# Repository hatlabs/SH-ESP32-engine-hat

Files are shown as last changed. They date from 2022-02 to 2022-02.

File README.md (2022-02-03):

# Engine Top Hat for SH-ESP32

This repository contains the hardware design files for the Engine Top Hat for SH-ESP32 (Engine Hat for short).

Engine Hat is a add-on circuit board that provides useful circuitry for connecting tachometers (RPM sensors), tank level sensors and engine alarms to an [SH-ESP32](https://hatlabs.github.io/sh-esp32).

The SH-ESP32 Engine Hat will be eventually available for purchase at [hatlabs.fi](https://hatlabs.fi).

Top view:

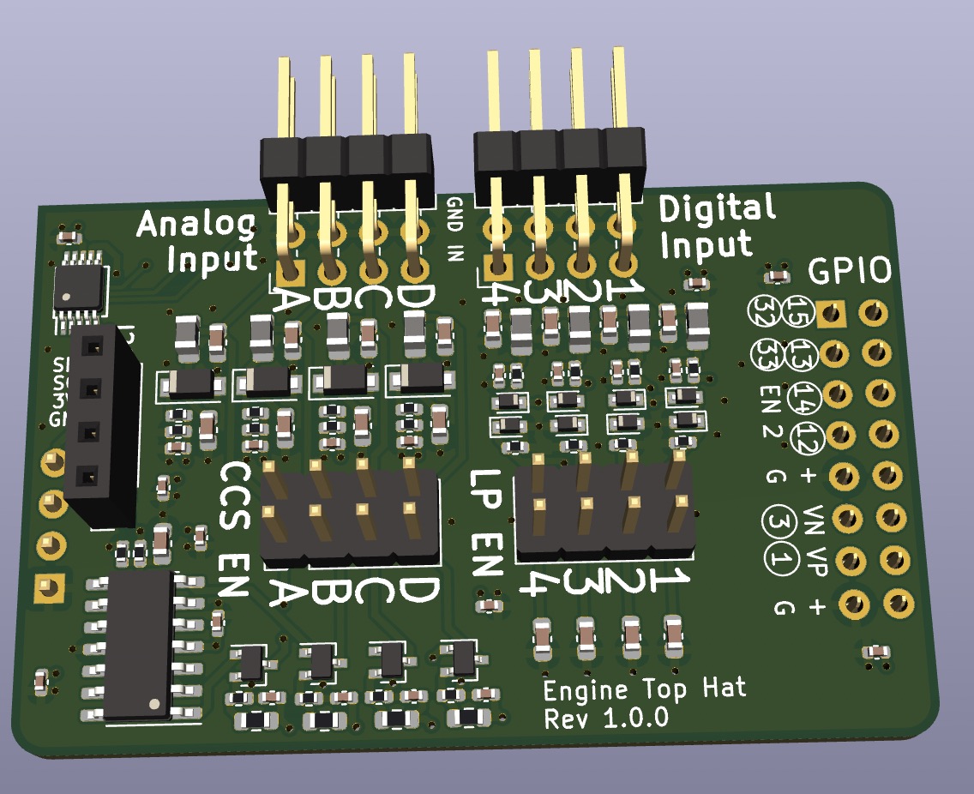
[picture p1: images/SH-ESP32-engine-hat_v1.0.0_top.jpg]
Rev 1.0.0 board, top view


Bottom view:

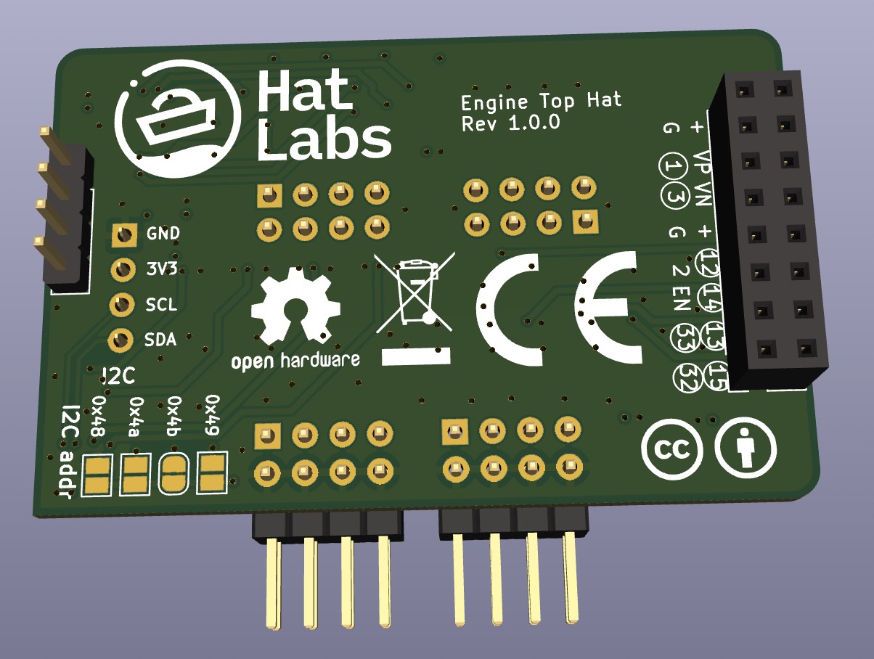
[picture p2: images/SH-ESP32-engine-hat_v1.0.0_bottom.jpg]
Rev 1.0.0 board, bottom view


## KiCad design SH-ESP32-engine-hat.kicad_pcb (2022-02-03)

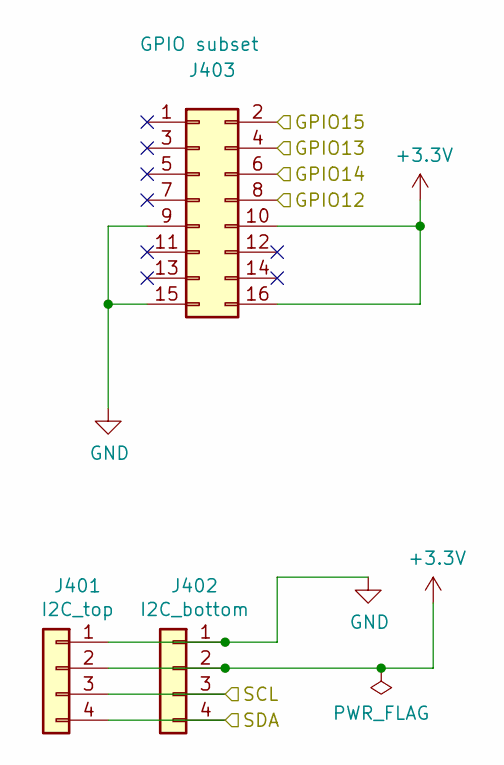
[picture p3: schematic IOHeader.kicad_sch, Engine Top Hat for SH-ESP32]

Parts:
J401: I2C_top; PinSocket_1x04_P2.54mm_Vertical; LCSC C225501
J402: I2C_bottom; PinHeader_1x04_P2.54mm_Vertical; LCSC C492403
J403: GPIO subset; PinSocket_2x08_P2.54mm_Vertical; LCSC C30734

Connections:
/Analog input/SCL: J401.3, J402.3; also elsewhere on the board
/Analog input/SDA: J401.4, J402.4; also elsewhere on the board
/DI1: J403.2; also elsewhere on the board
/DI2: J403.4; also elsewhere on the board
/DI3: J403.6; also elsewhere on the board
/DI4: J403.8; also elsewhere on the board
GND: J401.1, J402.1, J403.9, J403.15; also elsewhere on the board

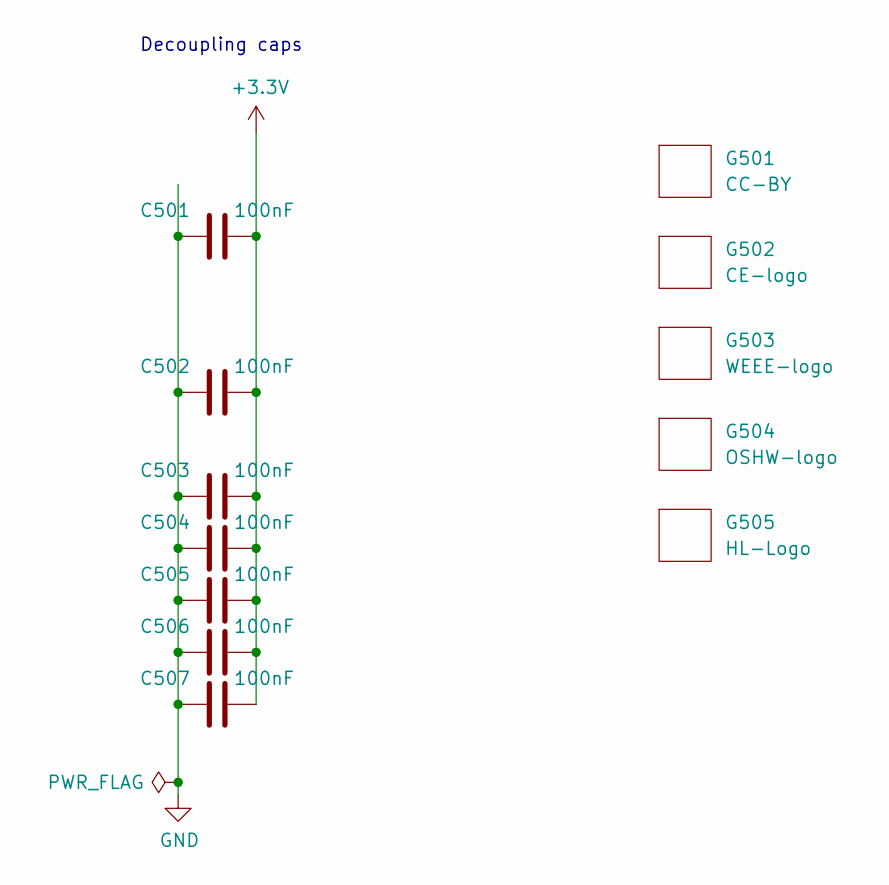
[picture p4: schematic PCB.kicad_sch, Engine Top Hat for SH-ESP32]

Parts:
C501, C502, C503, C504, C505, C506, C507: 100nF; C_0402_1005Metric; LCSC C1525
G501: CC-BY; cc-by_5mm
G502: CE-logo; CE-Logo_11.2x8mm_SilkScreen
G503: WEEE-logo; WEEE-Logo_5.6x8mm_SilkScreen
G504: OSHW-logo; OSHW-Logo2_9.8x8mm_SilkScreen
G505: HL-Logo; Hat_Labs_20mm

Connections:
GND: C501.1, C502.1, C503.1, C504.1, C505.1, C506.1, C507.1; also elsewhere on the board

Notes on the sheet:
Decoupling caps

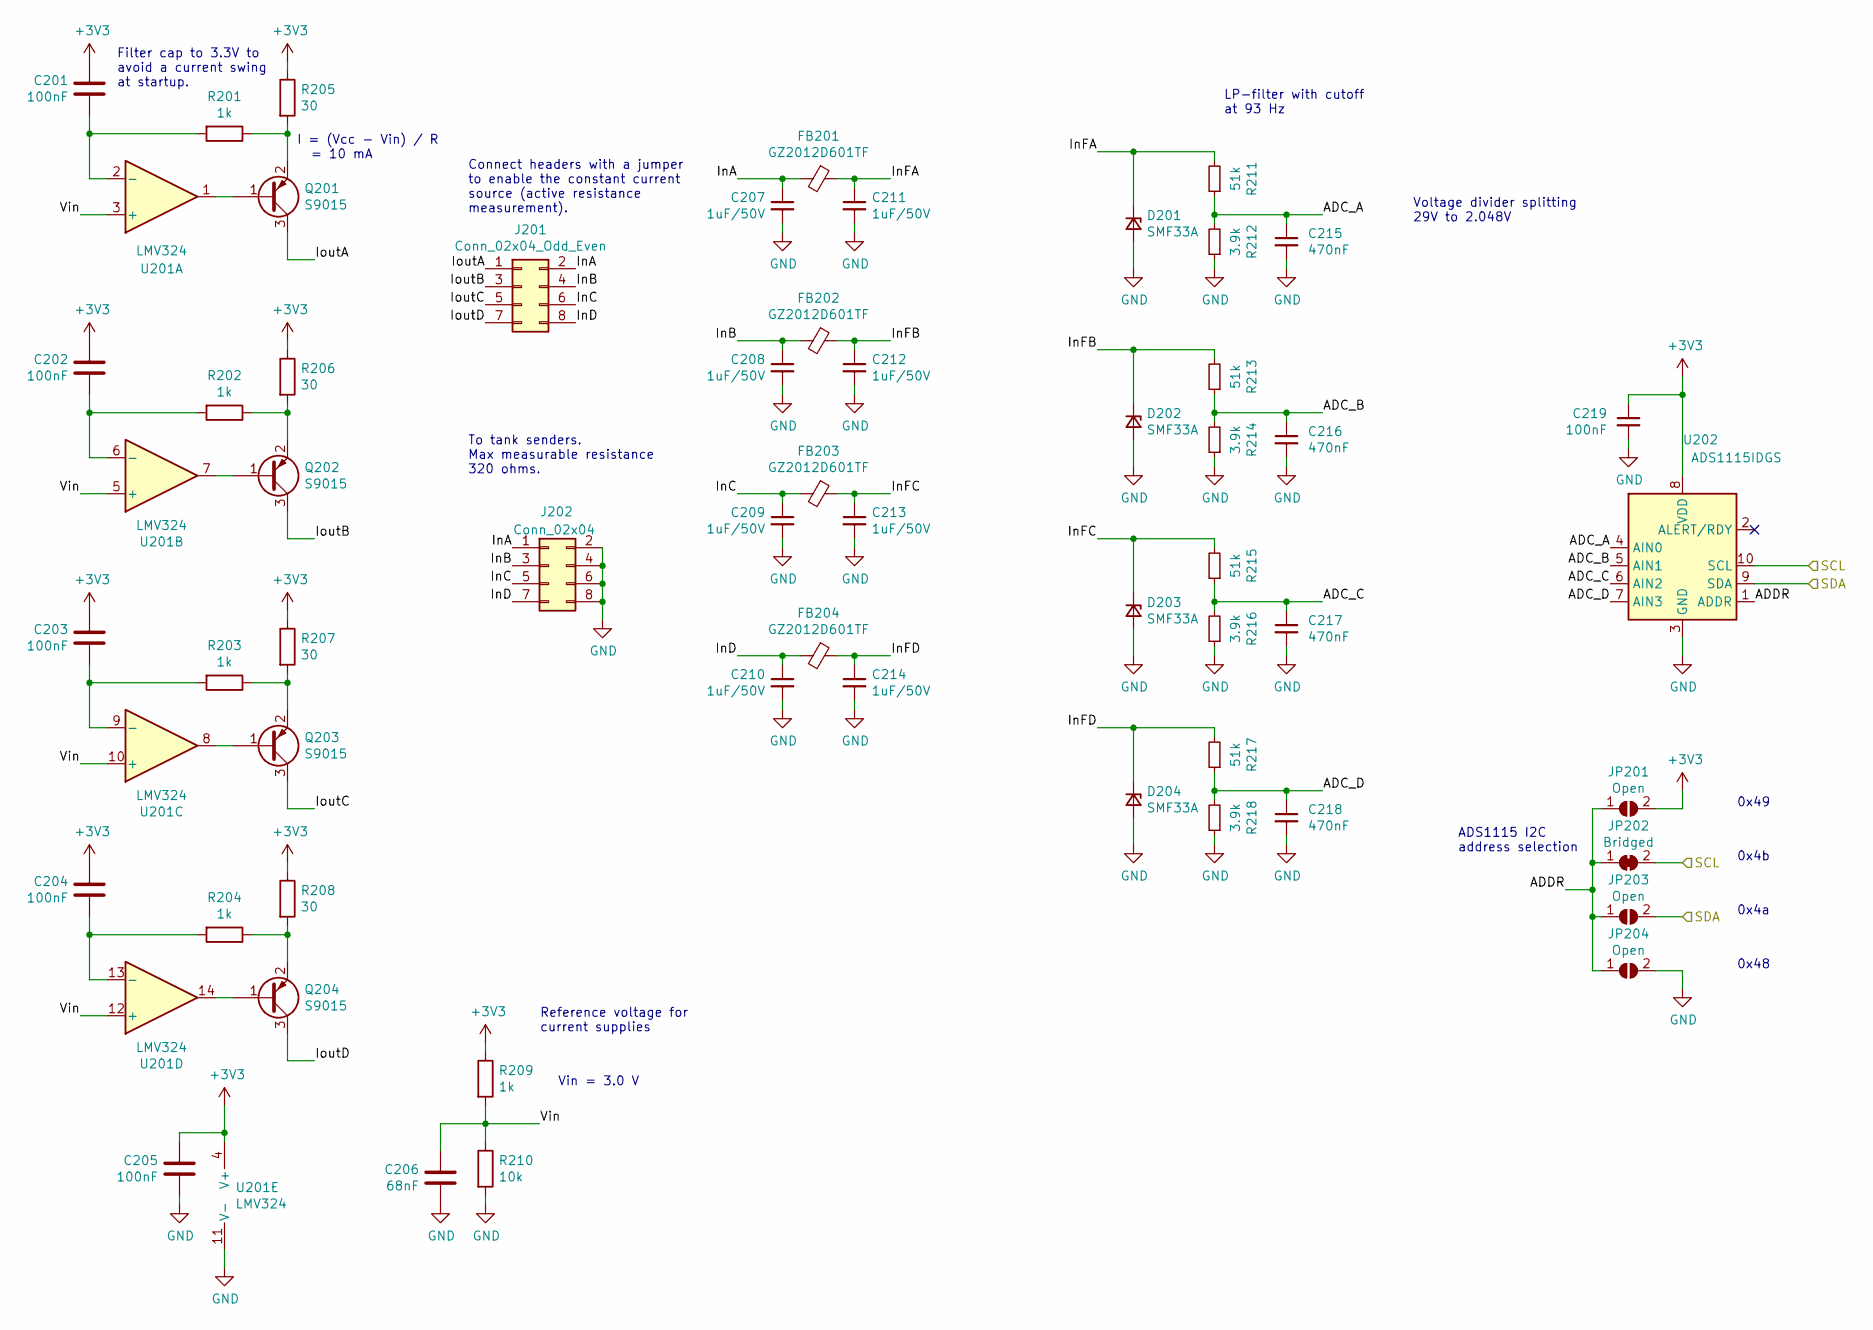
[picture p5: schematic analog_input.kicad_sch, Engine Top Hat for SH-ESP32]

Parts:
C201, C202, C203, C204, C205, C219: 100nF; C_0402_1005Metric; LCSC C1525
C206: 68nF; C_0603_1608Metric; LCSC C31658
C207, C208, C209, C210, C211, C212, C213, C214: 1uF/50V; C_0603_1608Metric; LCSC C15849
C215, C216, C217, C218: 470nF; C_0402_1005Metric; LCSC C47339
D201, D202, D203, D204: SMF33A; D_SOD-123F; LCSC C523840
FB201, FB202, FB203, FB204: GZ2012D601TF; L_0805_2012Metric; LCSC C1017
J201: Conn_02x04_Odd_Even; PinHeader_2x04_P2.54mm_Vertical; LCSC C124386
J202: Conn_02x04; PinHeader_2x04_P2.54mm_Horizontal; LCSC C358706
JP201, JP203, JP204: Open; SolderJumper-2_P1.3mm_Open_Pad1.0x1.5mm
JP202: Bridged; SolderJumper-2_P1.3mm_Bridged2Bar_RoundedPad1.0x1.5mm
Q201, Q202, Q203, Q204: S9015; SOT-323_SC-70; LCSC C106811
R201, R202, R203, R204, R209: 1k; R_0402_1005Metric; LCSC C11702
R205, R206, R207, R208: 30; R_0603_1608Metric; LCSC C22985
R210: 10k; R_0402_1005Metric; LCSC C25744
R211, R213, R215, R217: 51k; R_0402_1005Metric; LCSC C25794
R212, R214, R216, R218: 3.9k; R_0402_1005Metric; LCSC C51721
U201: LMV324; SOIC-14_3.9x8.7mm_P1.27mm; LCSC C362275
U202: ADS1115IDGS; TSSOP-10_3x3mm_P0.5mm; LCSC C37593

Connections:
/Analog input/ADC_A: C215.1, R211.1, R212.2, U202.4 (AIN0)
/Analog input/ADC_B: C216.1, R213.1, R214.2, U202.5 (AIN1)
/Analog input/ADC_C: C217.1, R215.1, R216.2, U202.6 (AIN2)
/Analog input/ADC_D: C218.1, R217.1, R218.2, U202.7 (AIN3)
/Analog input/ADDR: JP201.1 (A), JP202.1 (A), JP203.1 (A), JP204.1 (A), U202.1 (ADDR)
/Analog input/InA: C207.1, FB201.2, J201.2, J202.1
/Analog input/InB: C208.1, FB202.2, J201.4, J202.3
/Analog input/InC: C209.1, FB203.2, J201.6, J202.5
/Analog input/InD: C210.1, FB204.2, J201.8, J202.7
/Analog input/InFA: C211.1, D201.1 (K), FB201.1, R211.2
/Analog input/InFB: C212.1, D202.1 (K), FB202.1, R213.2
/Analog input/InFC: C213.1, D203.1 (K), FB203.1, R215.2
/Analog input/InFD: C214.1, D204.1 (K), FB204.1, R217.2
/Analog input/IoutA: J201.1, Q201.3 (C)
/Analog input/IoutB: J201.3, Q202.3 (C)
/Analog input/IoutC: J201.5, Q203.3 (C)
/Analog input/IoutD: J201.7, Q204.3 (C)
/Analog input/SCL: JP202.2 (B), U202.10 (SCL); also elsewhere on the board
/Analog input/SDA: JP203.2 (B), U202.9 (SDA); also elsewhere on the board
/Analog input/Vin: C206.1, R209.2, R210.1, U201.3 (+), U201.5 (+), U201.10 (+), U201.12 (+)
GND: C205.2, C206.2, C207.2, C208.2, C209.2, C210.2, C211.2, C212.2, C213.2, C214.2, C215.2, C216.2, C217.2, C218.2, C219.2, D201.2 (A), D202.2 (A), D203.2 (A), D204.2 (A), J202.2, J202.4, J202.6, J202.8, JP204.2 (B), R210.2, R212.1, R214.1, R216.1, R218.1, U201.11 (V-), U202.3 (GND); also elsewhere on the board
unnamed: C201.1, R201.2, U201.2 (-)
unnamed: C202.1, R202.2, U201.6 (-)
unnamed: C203.1, R203.2, U201.9 (-)
unnamed: C204.1, R204.2, U201.13 (-)
unnamed: Q201.1 (B), U201.1
unnamed: Q201.2 (E), R201.1, R205.2
unnamed: Q202.1 (B), U201.7
unnamed: Q202.2 (E), R202.1, R206.2
unnamed: Q203.1 (B), U201.8
unnamed: Q203.2 (E), R203.1, R207.2
unnamed: Q204.1 (B), U201.14
unnamed: Q204.2 (E), R204.1, R208.2

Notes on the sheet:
Vin = 3.0 V
ADS1115 I2C address selection
0x49
I = (Vcc - Vin) / R = 10 mA
Voltage divider splitting 29V to 2.048V
0x48
To tank senders. Max measurable resistance 320 ohms.
0x4a
Reference voltage for current supplies
0x4b
LP-filter with cutoff at 93 Hz
Connect headers with a jumper to enable the constant current source (active resistance measurement).
Filter cap to 3.3V to avoid a current swing at startup.

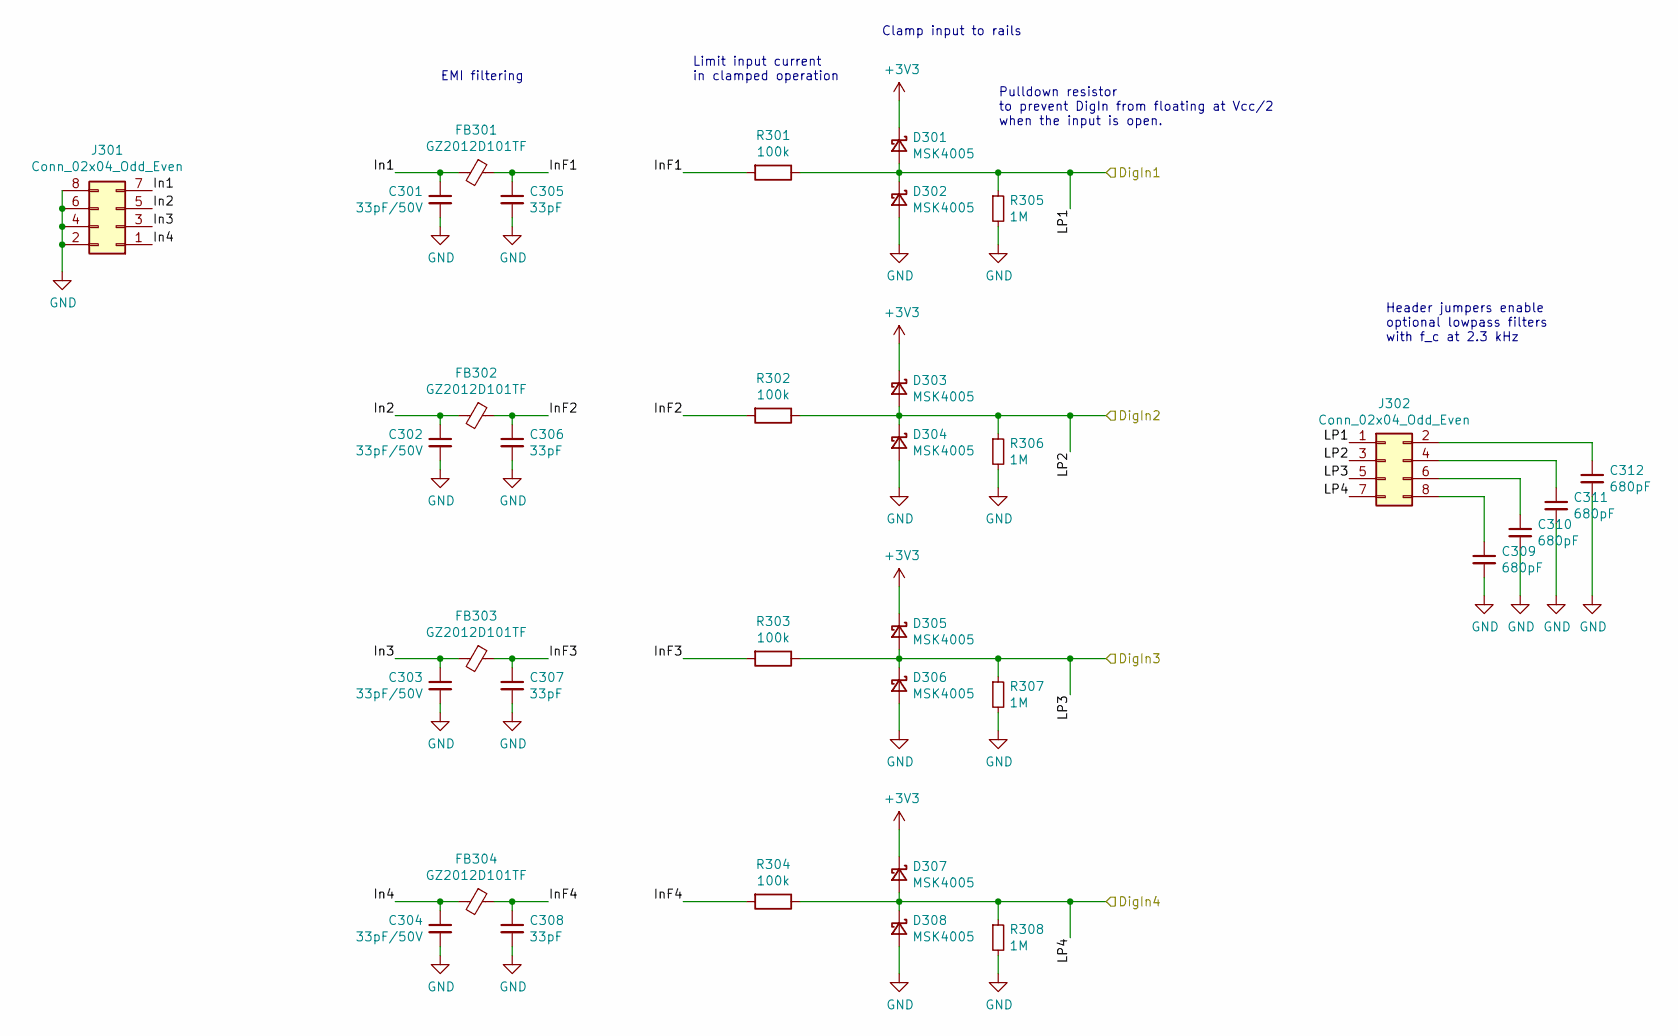
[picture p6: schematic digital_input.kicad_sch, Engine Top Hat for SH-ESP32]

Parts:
C301, C302, C303, C304: 33pF/50V; C_0603_1608Metric; LCSC C1663
C305, C306, C307, C308: 33pF; C_0402_1005Metric; LCSC C1562
C309, C310, C311, C312: 680pF; C_0603_1608Metric; LCSC C1630
D301, D302, D303, D304, D305, D306, D307, D308: MSK4005; D_SOD-523; LCSC C345957
FB301, FB302, FB303, FB304: GZ2012D101TF; L_0805_2012Metric; LCSC C1015
J301: Conn_02x04_Odd_Even; PinHeader_2x04_P2.54mm_Horizontal; LCSC C358706
J302: Conn_02x04_Odd_Even; PinHeader_2x04_P2.54mm_Vertical; LCSC C124386
R301, R302, R303, R304: 100k; R_0402_1005Metric; LCSC C25741
R305, R306, R307, R308: 1M; R_0402_1005Metric; LCSC C26083

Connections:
/DI1: D301.2 (A), D302.1 (K), J302.1, R301.1, R305.1; also elsewhere on the board
/DI2: D303.2 (A), D304.1 (K), J302.3, R302.1, R306.1; also elsewhere on the board
/DI3: D305.2 (A), D306.1 (K), J302.5, R303.1, R307.1; also elsewhere on the board
/DI4: D307.2 (A), D308.1 (K), J302.7, R304.1, R308.1; also elsewhere on the board
/Digital input/In1: C301.1, FB301.2, J301.7
/Digital input/In2: C302.1, FB302.2, J301.5
/Digital input/In3: C303.1, FB303.2, J301.3
/Digital input/In4: C304.1, FB304.2, J301.1
/Digital input/InF1: C305.1, FB301.1, R301.2
/Digital input/InF2: C306.1, FB302.1, R302.2
/Digital input/InF3: C307.1, FB303.1, R303.2
/Digital input/InF4: C308.1, FB304.1, R304.2
GND: C301.2, C302.2, C303.2, C304.2, C305.2, C306.2, C307.2, C308.2, C309.2, C310.2, C311.2, C312.2, D302.2 (A), D304.2 (A), D306.2 (A), D308.2 (A), J301.2, J301.4, J301.6, J301.8, R305.2, R306.2, R307.2, R308.2; also elsewhere on the board
unnamed: C309.1, J302.8
unnamed: C310.1, J302.6
unnamed: C311.1, J302.4
unnamed: C312.1, J302.2

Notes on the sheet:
Pulldown resistor to prevent DigIn from floating at Vcc/2 when the input is open.
EMI filtering
Clamp input to rails
Header jumpers enable optional lowpass filters with f_c at 2.3 kHz
Limit input current in clamped operation

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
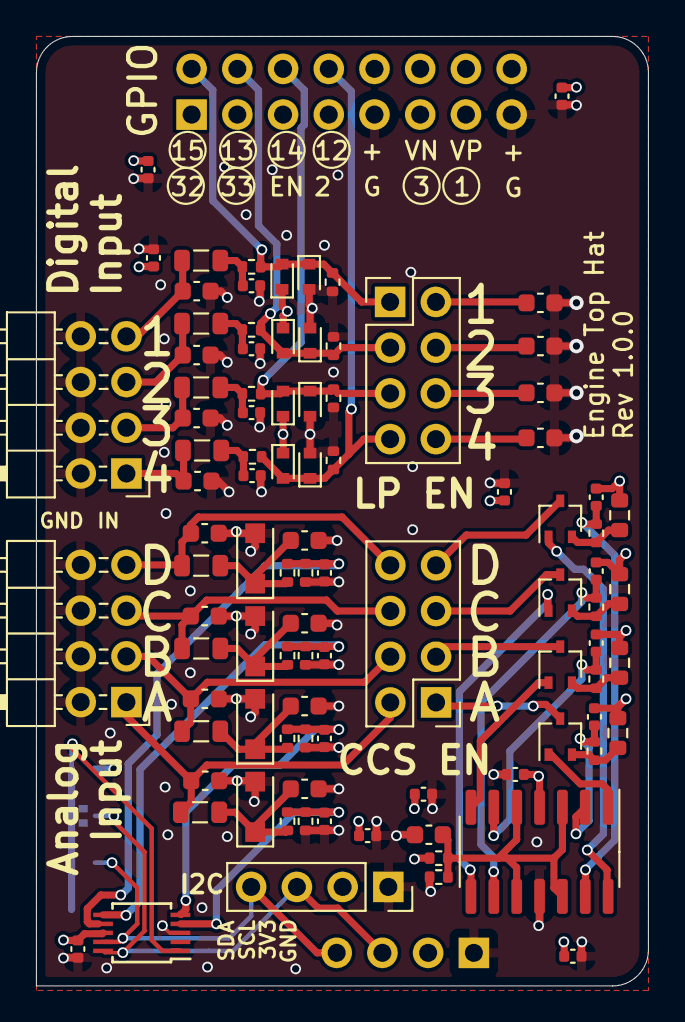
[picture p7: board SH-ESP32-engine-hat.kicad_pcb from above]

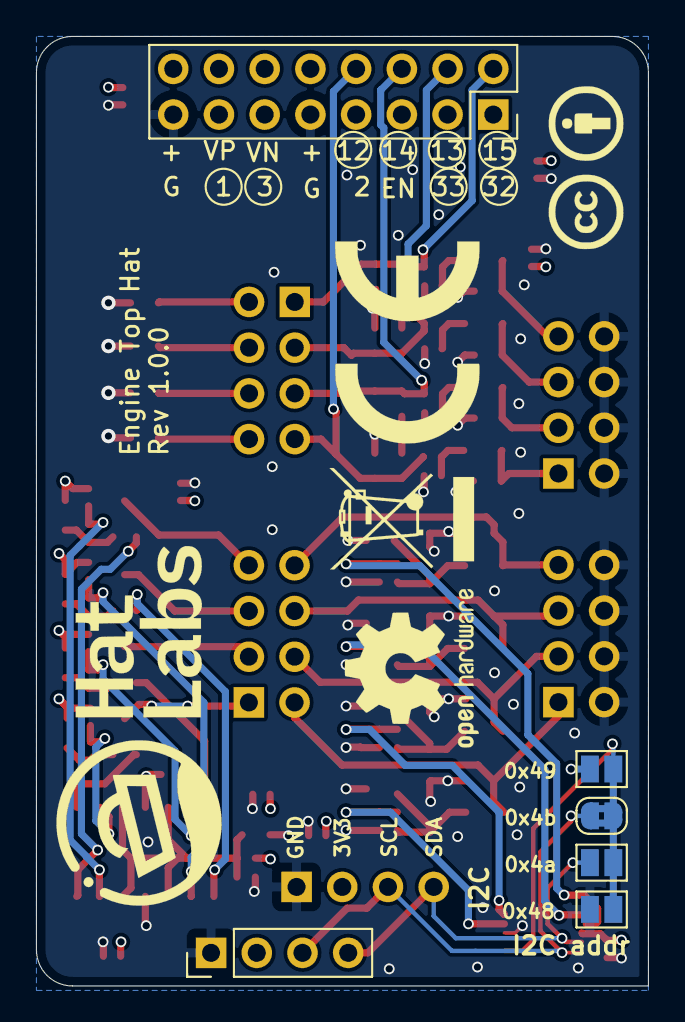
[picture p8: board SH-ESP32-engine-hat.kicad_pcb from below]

Board: 4 copper layers, 34.0 x 52.8 mm, 106 parts (11 on the bottom side), 50 nets.

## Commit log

2021-04-06 initial import
    [IOHeader.sch, PCB.sch, SH-ESP32-tank-hat.kicad_pcb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]
2021-04-21 Create schema for tank and RPM sensors
    [IOHeader.sch, PCB.sch, SH-ESP32-tank-hat.sch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]
2021-04-22 Initial PCB layout
    [IOHeader.sch, SH-ESP32-tank-hat.kicad_pcb, SH-ESP32-tank-hat.sch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]
2021-04-23 Reduce the PCB size; switch to TLA2024
    [IOHeader.sch, PCB.sch, SH-ESP32-tank-hat.kicad_pcb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]
2021-04-23 New design with only two channels and using ESP32 internal ADCs
    [IOHeader.sch, PCB.sch, SH-ESP32-tank-hat.kicad_pcb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]
2021-04-27 Add 4x optocoupler input for alarms and other use
    [IOHeader.sch, PCB.sch, SH-ESP32-tank-hat.kicad_pcb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]
2021-04-27 Update document metadata
    [IOHeader.sch, PCB.sch, SH-ESP32-tank-hat.kicad_pcb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]
2021-04-27 Make all TH headers virtual
    [SH-ESP32-engine-hat.kicad_pcb]
2021-04-27 Fix the footprint for ELQ3H7
    [SH-ESP32-engine-hat.kicad_pcb, optocoupler_input.sch]
2021-04-27 Change opto top conx from a socket to a header
    [IOHeader.sch, SH-ESP32-engine-hat.kicad_pcb]
2021-04-28 Fix the wrong LCSC component for R501
    Also silkscreen fixes
    [SH-ESP32-engine-hat.kicad_pcb, rpm_sender.sch]
2021-05-20 Fix the reversed tank input B opto inputs
    [IOHeader.sch, SH-ESP32-engine-hat.kicad_pcb, SH-ESP32-engine-hat.sch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]
2021-07-03 Redesign with unisolated inputs
    [IOHeader.sch, PCB.sch, SH-ESP32-engine-hat.kicad_pcb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]
2021-08-16 Change DIP switches to headers
    [IOHeader.sch, PCB.sch, SH-ESP32-engine-hat.kicad_pcb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]
2021-08-16 Routing fixes
    [SH-ESP32-engine-hat.kicad_pcb]
2021-08-17 Add solder pads for I2C address selection
    Also pre-emptive CE mark
    [PCB.sch, SH-ESP32-engine-hat.kicad_pcb, analog_input.sch]
2021-12-31 Fix JLCPCB tooling hole footprint
    [SH-ESP32-engine-hat.kicad_pcb]
2021-12-31 Bump version number
    [IOHeader.sch, PCB.sch, SH-ESP32-engine-hat.kicad_pcb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]
2021-12-31 Save in KiCad 6 format
    [IOHeader.kicad_sch, IOHeader.sch, PCB.kicad_sch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]
2021-12-31 Fix DRC errors
    [IOHeader.kicad_sch, PCB.kicad_sch, SH-ESP32-engine-hat.kicad_pcb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]
2022-02-02 Bump the version number
    [IOHeader.kicad_sch, PCB.kicad_sch, SH-ESP32-engine-hat.kicad_pcb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]
2022-02-02 Remove tooling holes
    [PCB.kicad_sch, SH-ESP32-engine-hat.kicad_pcb, SH-ESP32-engine-hat.kicad_sch]
2022-02-02 Crop the copper zones to PCB area
    [SH-ESP32-engine-hat.kicad_pcb]
2022-02-02 Fix solder jumper silkscreen
    [SH-ESP32-engine-hat.kicad_pcb]
2022-02-03 Add PCB graphics as symbols
    [PCB.kicad_sch, SH-ESP32-engine-hat.kicad_pcb, SH-ESP32-engine-hat.kicad_sch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]
2022-02-03 Add the KiKit footprint library
2022-02-03 Add panel tab annotations
    [SH-ESP32-engine-hat.kicad_pcb]
2022-02-03 Refill zones, remove JLC order number template
    [SH-ESP32-engine-hat.kicad_pcb]
2022-02-03 Replace C211-214 with 50V 0603 footprint parts
    [SH-ESP32-engine-hat.kicad_pcb, SH-ESP32-engine-hat.kicad_sch, analog_input.kicad_sch]
2022-02-03 Update sheet data; refill
    [IOHeader.kicad_sch, PCB.kicad_sch, SH-ESP32-engine-hat.kicad_pcb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]

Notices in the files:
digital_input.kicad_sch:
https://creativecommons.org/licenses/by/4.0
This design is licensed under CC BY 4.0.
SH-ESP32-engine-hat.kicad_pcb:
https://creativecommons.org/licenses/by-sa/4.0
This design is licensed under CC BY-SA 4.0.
